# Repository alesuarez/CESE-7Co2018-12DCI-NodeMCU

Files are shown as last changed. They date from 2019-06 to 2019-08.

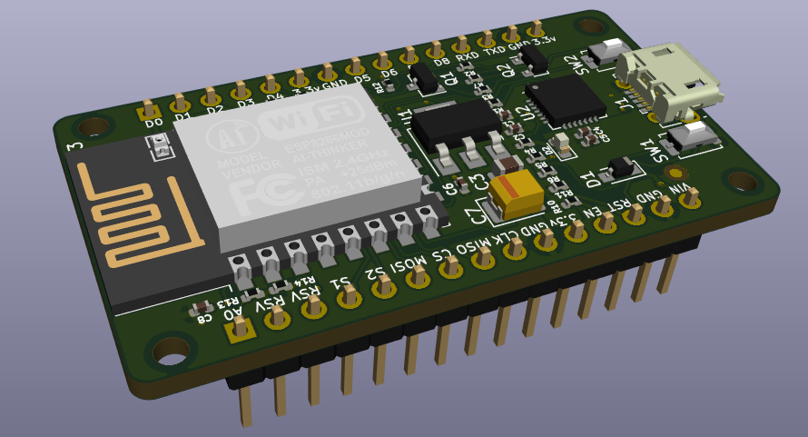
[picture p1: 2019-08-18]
views/nodeMCU2.png

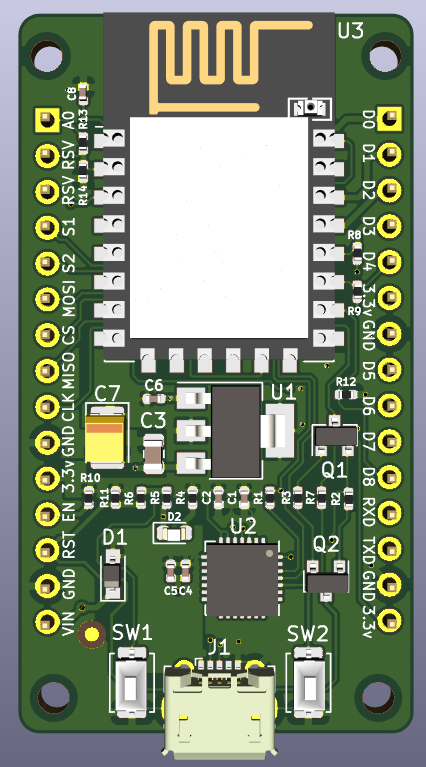
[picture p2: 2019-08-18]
views/nodeMCU.png

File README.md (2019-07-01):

CESE-7Co2018-12DCI
===================

Replica nodeMCU
---------------

- https://github.com/nodemcu/nodemcu-devkit-v1.0

## Designator & Parameter

|Designator|Parameter|
|-|-|
|C1,C4,C6 |100nF (104) ±10% 16V|
|C2 |100uF(107) ±10% 6.3V Case B 3528|
|C3,C5,C8 |10uF(106) ±20% 10V |
|C7|10uF(106) ±10% 25V|
|D1|SOD-123 40V,1A,VF=0.45V@1A|
|LED1|1.6x0.8x0.6 Iv= 35~65mcd @IF=5mA ESD:1000V |
|R1,R2,R3,R4,R5,R7,R8|12KΩ (1202) ±1% 0.0625W [50V TYP] [100V MAX] T.C.R ±100|
|R6,R9,R11,R12|470Ω (4700) ±1% 0.0625W [50V TYP] [100V MAX] T.C.R ±100|
|R10(Do not install)|0Ω (0R00) ±1% 0.0625W [50V TYP] [100V MAX] T.C.R ±100|
|R13|220kΩ (2203) ±1% 0.0625W [50V TYP] [100V MAX] T.C.R ±100|
|R14|100kΩ (1003) ±1% 0.0625W [50V TYP] [100V MAX] T.C.R ±100|

Diseño de circuitos integrados
------------------------------

### AUTOR ###

- Suarez, Sebastian Alejandro

### REVISOR ###

- Ferreyra, Hernan

DISEÑO
------

Ver carperta OUT

Planilla de revision
--------------------

https://docs.google.com/spreadsheets/d/1GdUnNvNa7OGYix6WSLJ_TsLkDbuR13YAUQkwYhvH5Zk/edit?usp=sharing

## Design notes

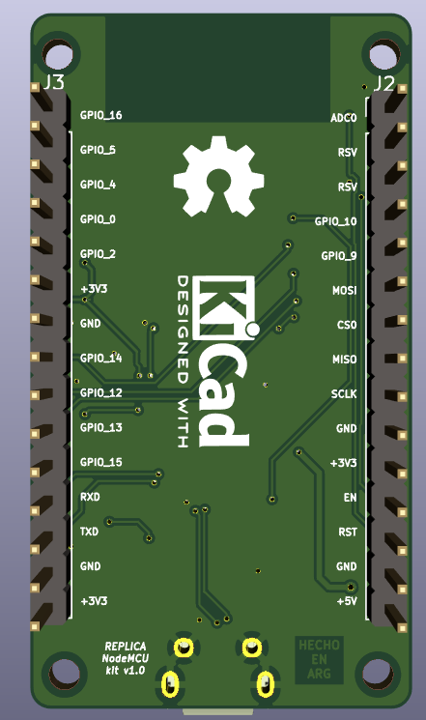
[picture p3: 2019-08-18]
views/nodeMCU_back.png

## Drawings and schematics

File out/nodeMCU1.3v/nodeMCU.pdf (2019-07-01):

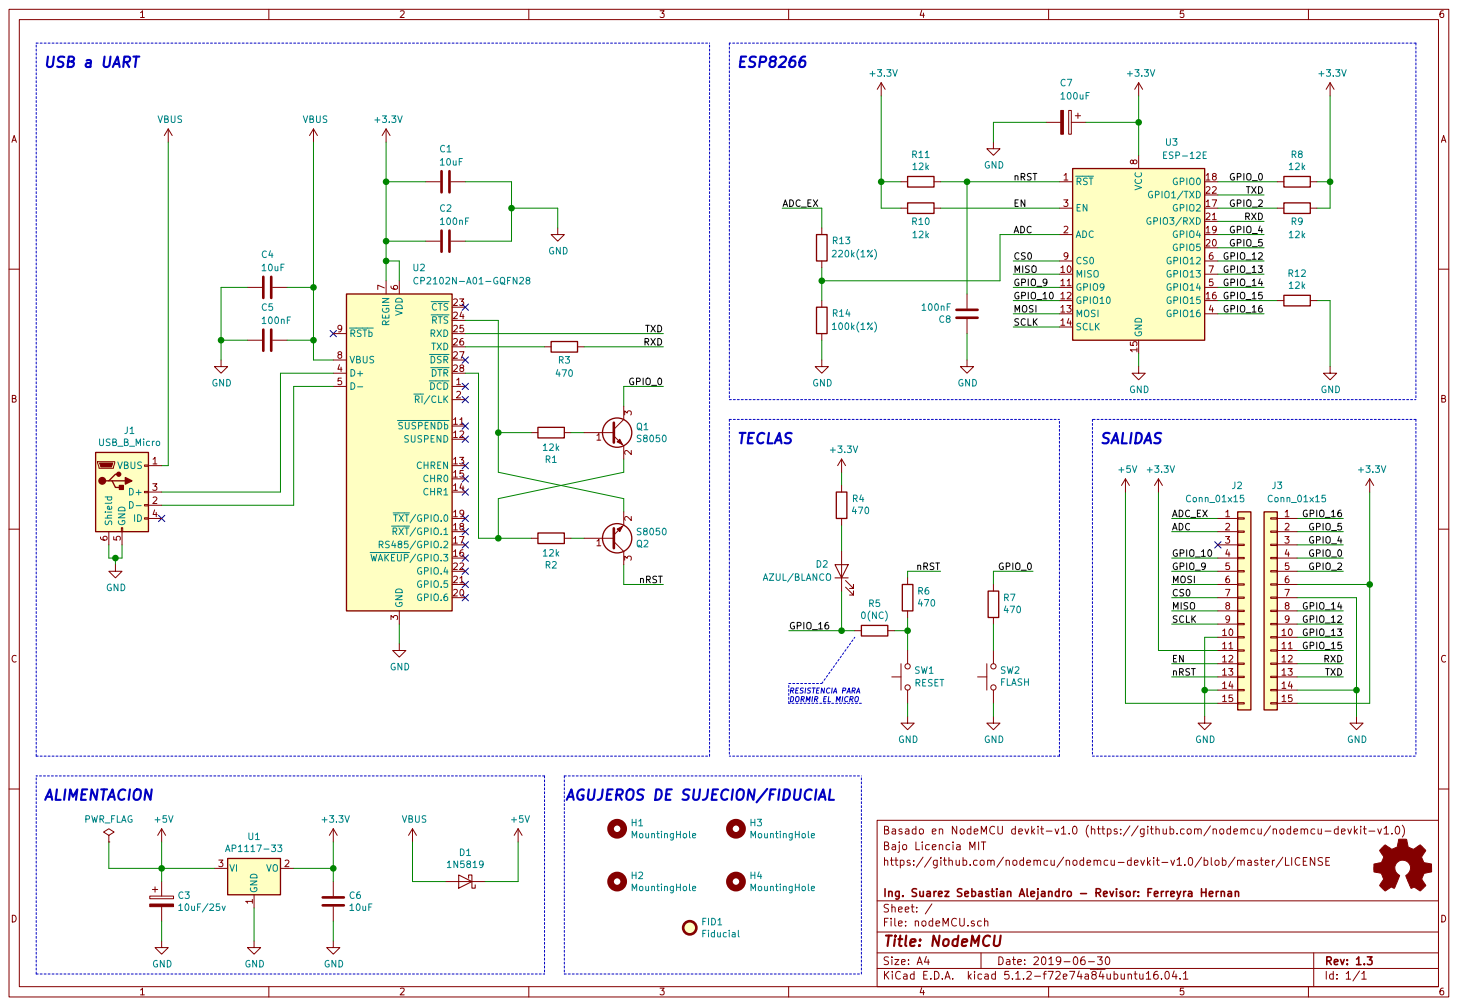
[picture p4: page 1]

7 VBUS 8 RSTb 9 U2CP2102N-A01-GQFN28 USB a UART ESP8266

Basado en NodeMCU devkit-v1.0 (https://github.com/nodemcu/nodemcu-devkit-v1.0) R1

AGUJEROS DE SUJECION/FIDUCIAL

Bajo Licencia MIT
https://github.com/nodemcu/nodemcu-devkit-v1.0/blob/master/LICENSE

Ing. Suarez Sebastian Alejandro - Revisor: Ferreyra Hernan
File: nodeMCU.sch Sheet: /
Id: 1/1 Title: NodeMCU

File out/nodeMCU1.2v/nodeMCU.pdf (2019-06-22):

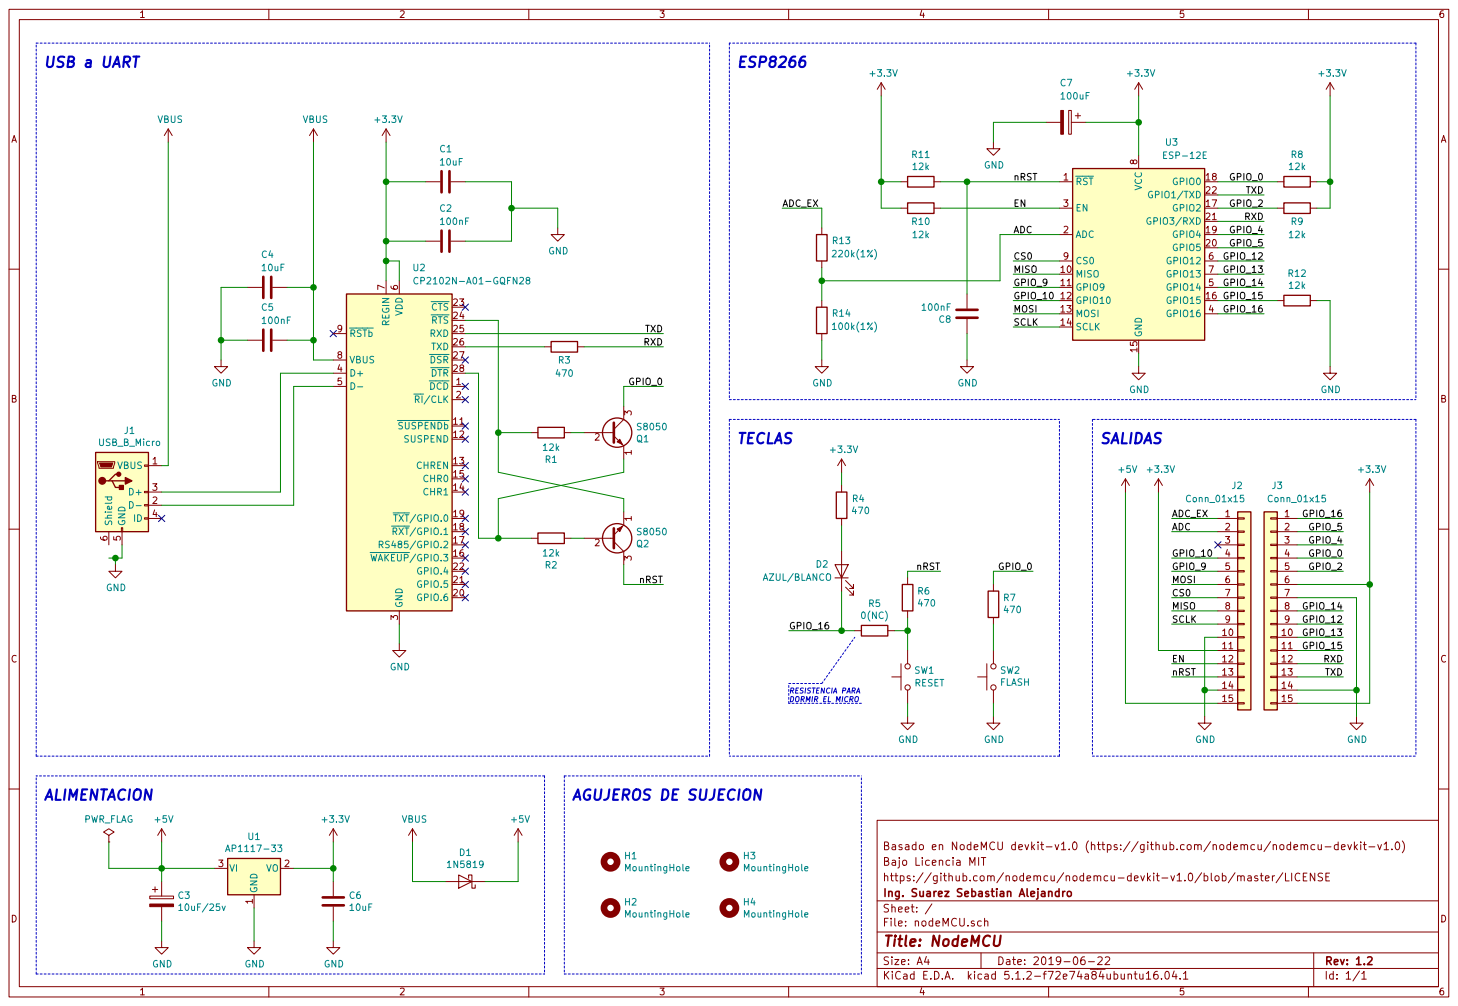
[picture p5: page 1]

7 VBUS 8 RSTb 9 U2CP2102N-A01-GQFN28 USB a UART ESP8266

Basado en NodeMCU devkit-v1.0 (https://github.com/nodemcu/nodemcu-devkit-v1.0) 1

Bajo Licencia MIT
https://github.com/nodemcu/nodemcu-devkit-v1.0/blob/master/LICENSE
Ing. Suarez Sebastian Alejandro
File: nodeMCU.sch Sheet: /
Id: 1/1 Title: NodeMCU

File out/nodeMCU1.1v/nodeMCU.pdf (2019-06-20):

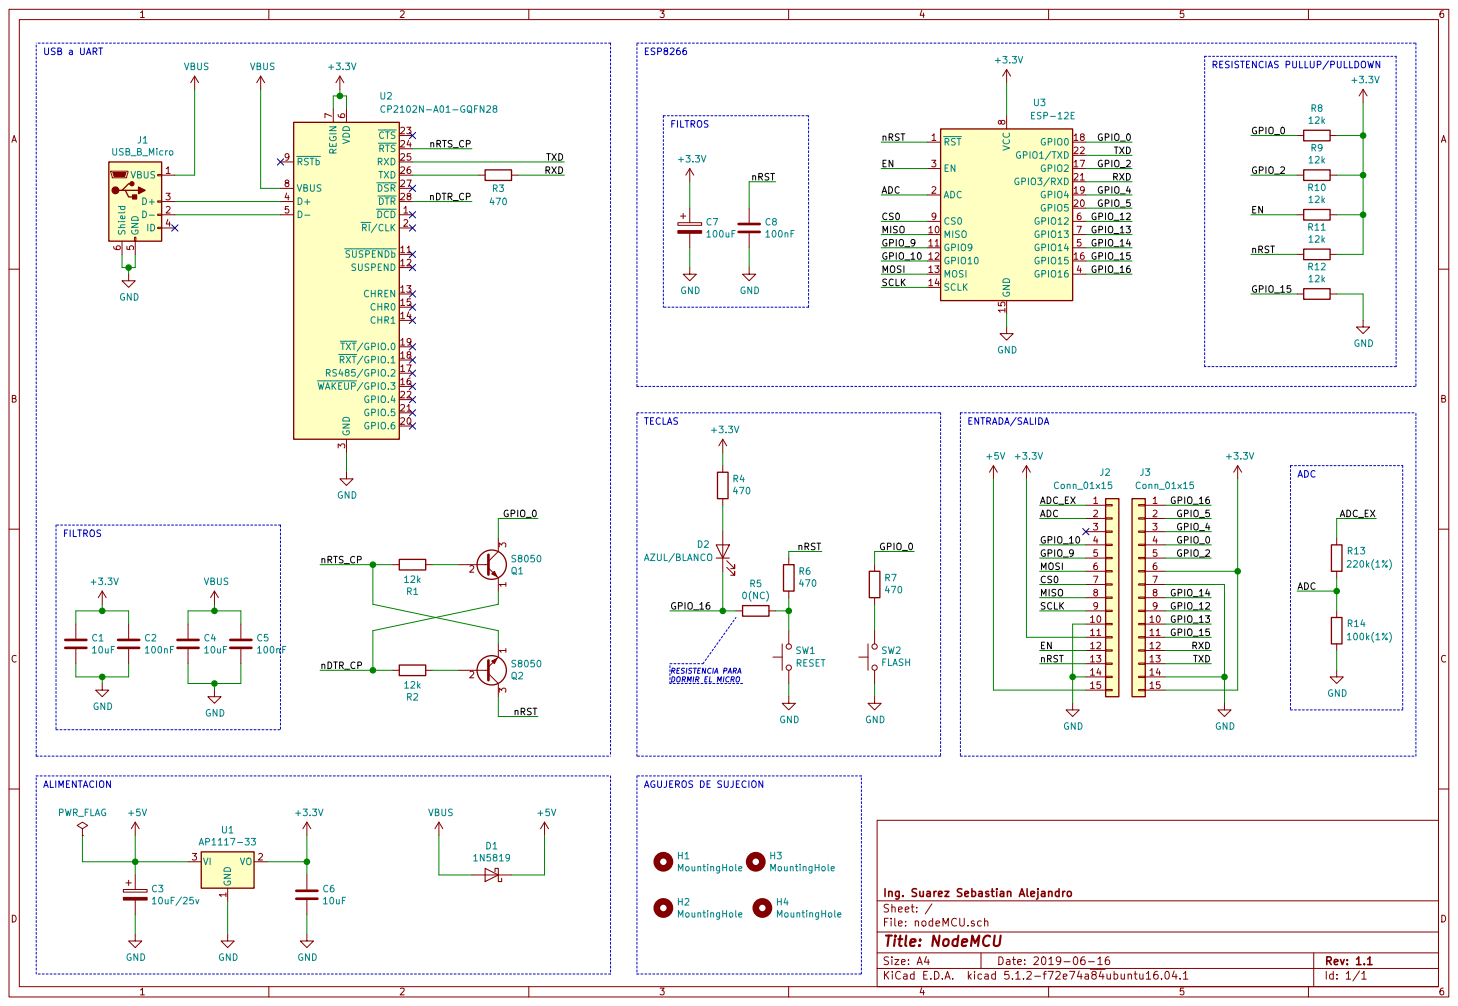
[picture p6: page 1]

7 VBUS 8 RSTb 9 U2CP2102N-A01-GQFN28 USB a UART

ESP8266

FILTROS

RESISTENCIA PARA DORMIR EL MICRO

Ing. Suarez Sebastian Alejandro
File: nodeMCU.sch Sheet: /
Id: 1/1 Title: NodeMCU

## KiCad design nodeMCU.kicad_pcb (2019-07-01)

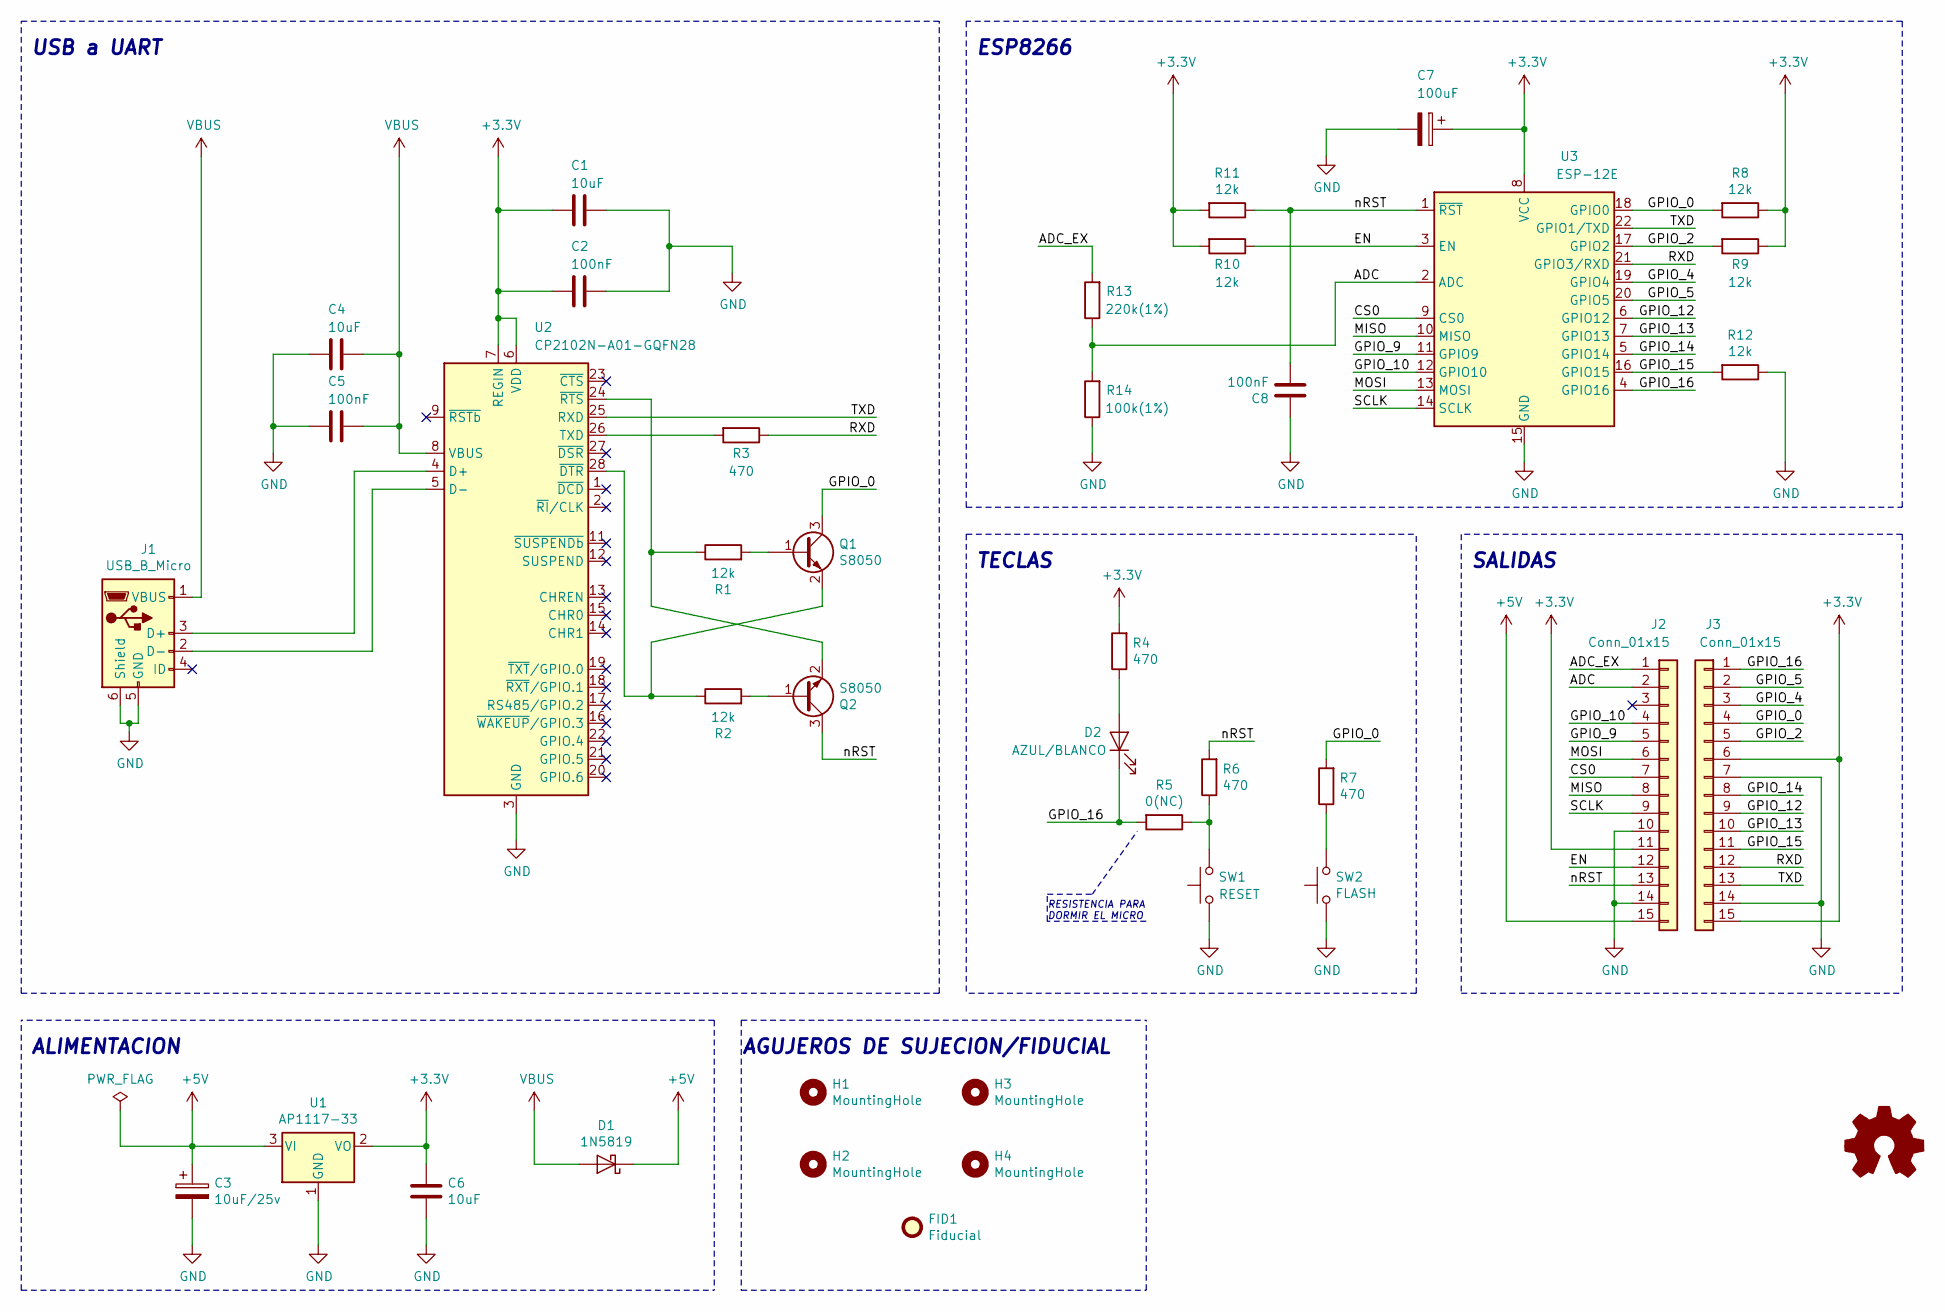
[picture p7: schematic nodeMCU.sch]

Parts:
C1, C4, C6: 10uF; C_0402_1005Metric
C2, C5, C8: 100nF; C_0402_1005Metric
C3: 10uF/25v; C_0805_2012Metric
C7: 100uF; CP_EIA-3528-21_Kemet-B
D1: 1N5819; D_SOD-323_HandSoldering
D2: AZUL/BLANCO; LED_0603_1608Metric
FID1: Fiducial; Fiducial_1mm_Mask2mm
H1, H2, H3, H4: MountingHole; MountingHole_2.2mm_M2
J1: USB_B_Micro; USB_Micro-B_Molex-105017-0001
J2, J3: Conn_01x15; PinHeader_1x15_P2.54mm_Vertical
Q1, Q2: S8050; SOT-23
R1, R2, R8, R9, R10, R11, R12: 12k; R_0402_1005Metric
R3, R4, R6, R7: 470; R_0402_1005Metric
R5: 0(NC); R_0402_1005Metric
R13: 220k(1%); R_0402_1005Metric
R14: 100k(1%); R_0402_1005Metric
SW1: RESET; SW_Push_SPST_NO_Alps_SKRK
SW2: FLASH; SW_Push_SPST_NO_Alps_SKRK
U1: AP1117-33; SOT-223-3_TabPin2
U2: CP2102N-A01-GQFN28; QFN-28-1EP_5x5mm_P0.5mm_EP3.35x3.35mm
U3: ESP-12E

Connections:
+3V3: C1.2, C2.2, C6.1, C7.1, J2.11, J3.6, J3.15, R4.2, R8.1, R9.1, R10.2, R11.2, U1.2 (VO), U2.6 (VDD), U2.7 (REGIN), U3.8 (VCC)
+5V: C3.1, D1.1 (K), J2.15, U1.3 (VI)
/ADC: J2.2, R13.1, R14.2, U3.2 (ADC)
/ADC_EX: J2.1, R13.2
/CS0: J2.7, U3.9 (CS0)
/EN: J2.12, R10.1, U3.3 (EN)
/GPIO_0: J3.4, Q1.3 (C), R7.2, R8.2, U3.18 (GPIO0)
/GPIO_2: J3.5, R9.2, U3.17 (GPIO2)
/GPIO_4: J3.3, U3.19 (GPIO4)
/GPIO_5: J3.2, U3.20 (GPIO5)
/GPIO_9: J2.5, U3.11 (GPIO9)
/GPIO_10: J2.4, U3.12 (GPIO10)
/GPIO_12: J3.9, U3.6 (GPIO12)
/GPIO_13: J3.10, U3.7 (GPIO13)
/GPIO_14: J3.8, U3.5 (GPIO14)
/GPIO_15: J3.11, R12.2, U3.16 (GPIO15)
/GPIO_16: D2.1 (K), J3.1, R5.2, U3.4 (GPIO16)
/MISO: J2.8, U3.10 (MISO)
/MOSI: J2.6, U3.13 (MOSI)
/RXD: J3.12, R3.1, U3.21 (GPIO3/RXD)
/SCLK: J2.9, U3.14 (SCLK)
/TXD: J3.13, U2.25 (RXD), U3.22 (GPIO1/TXD)
/nDTR_CP: Q1.2 (E), R2.1, U2.28 (~DTR)
/nRST: C8.2, J2.13, Q2.3 (C), R6.2, R11.1, U3.1 (~RST)
/nRTS_CP: Q2.2 (E), R1.1, U2.24 (~RTS)
GND: C1.1, C2.1, C3.2, C4.2, C5.2, C6.2, C7.2, C8.1, J1.5 (GND), J1.6 (Shield), J2.10, J2.14, J3.7, J3.14, R12.1, R14.1, SW1.1, SW2.1, U1.1 (GND), U2.3 (GND), U2.29 (GND), U3.15 (GND)
unnamed: D2.2 (A), R4.1
unnamed: J1.2 (D-), U2.5 (D-)
unnamed: J1.3 (D+), U2.4 (D+)
unnamed: Q1.1 (B), R1.2
unnamed: Q2.1 (B), R2.2
unnamed: R3.2, U2.26 (TXD)
unnamed: R5.1, R6.1, SW1.2
unnamed: R7.1, SW2.2
VBUS: C4.1, C5.1, D1.2 (A), J1.1 (VBUS), U2.8 (VBUS)

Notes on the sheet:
USB a UART
ESP8266
AGUJEROS DE SUJECION/FIDUCIAL
SALIDAS
TECLAS
RESISTENCIA PARA DORMIR EL MICRO
ALIMENTACION

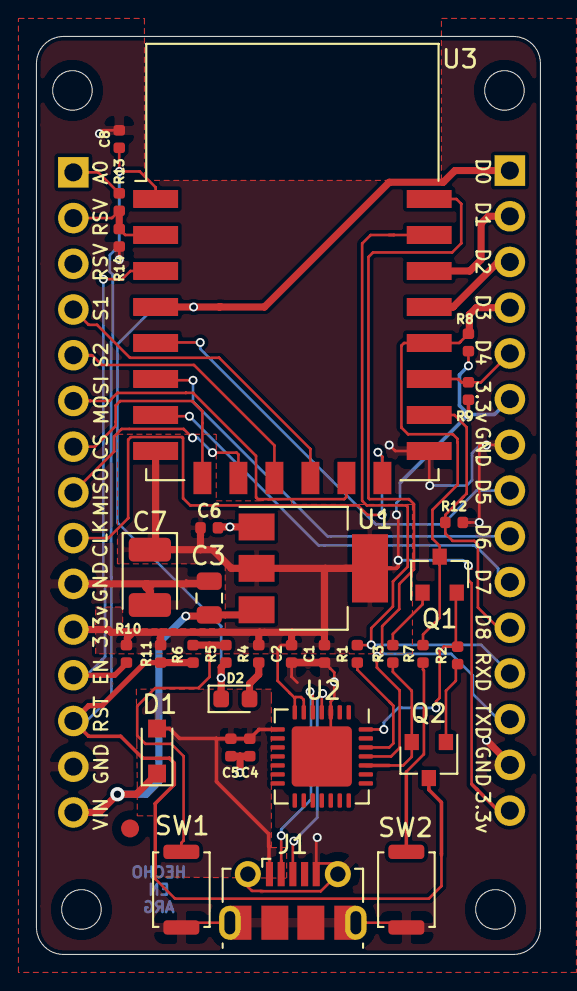
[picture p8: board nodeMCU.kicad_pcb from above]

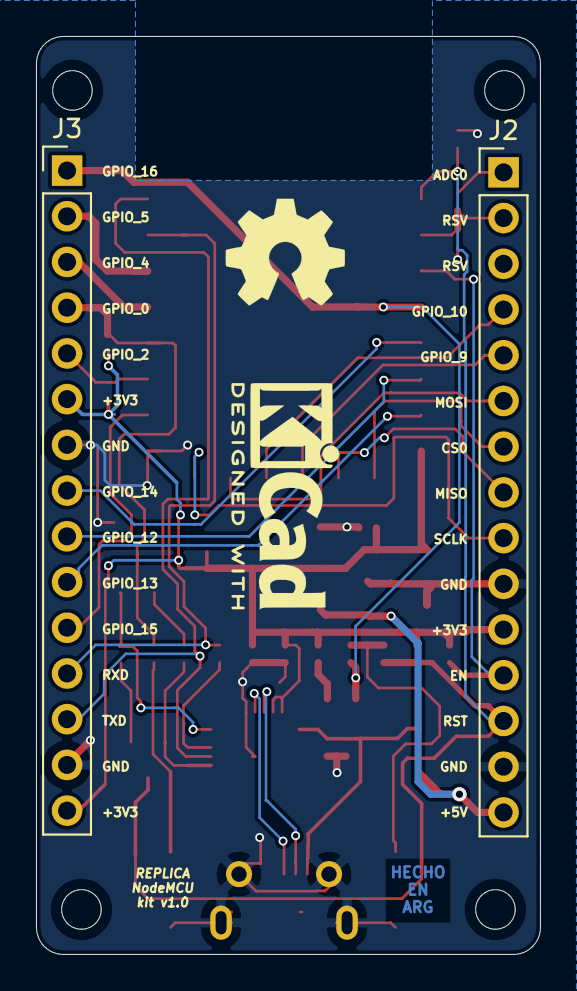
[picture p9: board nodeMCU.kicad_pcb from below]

Board: 2 copper layers, 28.0 x 51.0 mm, 39 parts (2 on the bottom side), 35 nets.

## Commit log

2019-06-08 Esquematico sin etiquetas - Una sola hoja
    [nodeMCU.kicad_pcb, nodeMCU.sch, usb_to_uart.sch]
2019-06-12 Primera version de esquematico terminada
    [nodeMCU.sch]
2019-06-16 Terminada la revision 1.1 + rule check
    [nodeMCU.sch, usb_to_uart.sch]
2019-06-20 Agrego valores a los componentes
    [nodeMCU.sch]
2019-06-20 Agrego footprints
    [nodeMCU.sch]
2019-06-20 Ubicacion componentes en la placa + corte curvo del PCB
2019-06-20 Agrego agujeros de sujecion esquematico + pcb
    [nodeMCU.kicad_pcb, nodeMCU.sch]
2019-06-20 Arreglo bordes de corte redondeados + ubico agujeros de sujecion
    [nodeMCU.kicad_pcb]
2019-06-20 Corrijo footprint de diodo D1
    [nodeMCU.sch]
2019-06-21 Comienzo el ruteo
    [nodeMCU.kicad_pcb]
2019-06-22 Cambios propuesto por el docente en el esquematico
    [nodeMCU.kicad_pcb, nodeMCU.sch]
2019-06-22 Agrego mas cambios propuestos por el docente en el esquematico
2019-06-22 Borro ruteo
    [nodeMCU.kicad_pcb, nodeMCU.sch]
2019-06-22 Termino el ruteo
    [nodeMCU.kicad_pcb, nodeMCU.sch]
2019-06-23 Agregp logos
    [nodeMCU.kicad_pcb, nodeMCU.sch]
2019-06-23 Agrego bvistas 3ds
    [nodeMCU.kicad_pcb]
2019-06-23 PCB Terminado
    [nodeMCU.kicad_pcb, nodeMCU.sch]
2019-06-26 Agrego fiducial
    [nodeMCU.kicad_pcb, nodeMCU.sch]
2019-06-26 Agrego numero de partes
    [nodeMCU.sch]
2019-06-26 Agrego numeros de parte y numero de digikey
    [nodeMCU.sch]
2019-06-26 Terminado el PCB
    [nodeMCU.kicad_pcb]
2019-06-29 Agrego comentarios del Docente
    [nodeMCU.kicad_pcb]
2019-07-01 Correcciones propuestas II
    [nodeMCU.kicad_pcb, nodeMCU.sch]
2019-07-01 Correcciones finales segun el docente
    [nodeMCU.kicad_pcb]
2019-07-01 Terminada version 1.3v
